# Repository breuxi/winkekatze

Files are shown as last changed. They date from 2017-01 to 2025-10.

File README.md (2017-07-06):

## ESP8266 enabled lucky cat

Code derived from https://github.com/themad/jimmykater

### Changes:
* Keeps lights on. So, continuous lighting.
* More light effects
* Keeps original waving mechanism. ( Instead of using a Servo )
* mqtt authentication support (can be configured in wifi captive portal)
* a lot of stuff

### MQTT Topics:

* catname/eye/mode/set   [solid|warp|blink]
* catname/eye/speed/set  [slow|med|fast]
* catname/eye/color/set  [dark|white|red|green|blue|yellow|cyan|pink]
* catname/paw/command    [wink|nowink]

### Demo Time!

<iframe src="https://player.vimeo.com/video/198570621" width="640" height="360" frameborder="0" webkitallowfullscreen mozallowfullscreen allowfullscreen></iframe>
<p><a href="https://vimeo.com/198570621">Monicat</a> from <a href="https://vimeo.com/user1086940">Bjoern Pohl</a> on <a href="https://vimeo.com">Vimeo</a>.</p>

### Hardware

Pinouts are currently set to a wemos d1 mini which fits nicely into such a cat. But I guess any 8266 excep a ESP01 will do it somehow. 

* 8266 : Wemos D1 Mini
  * at least three GPIOs:
    * "Force Setup" Button
    * LED Data input (only one for both leds, both could(!) be controlled individually, anyway.
    * Waving "electronic" from Cat :)
* pushbutton ( "force setup button")
* Cat : 22cm (~9 inch) lucky cat
* Adafruit addressable LEDs: https://www.sparkfun.com/products/12999
* 220 Ohm Resistor in Data line to the LEDs.
* A lot of hot glue.

The Sketch uses the famous [WifiManager](https://github.com/tzapu/WiFiManager). If you press the "force setup button" while powering the device, it'll loose all of it's settings and will fall back into WifiManager's AP mode.

Original lucky cat electronic can directly be driven by gpio (4-10mAh).

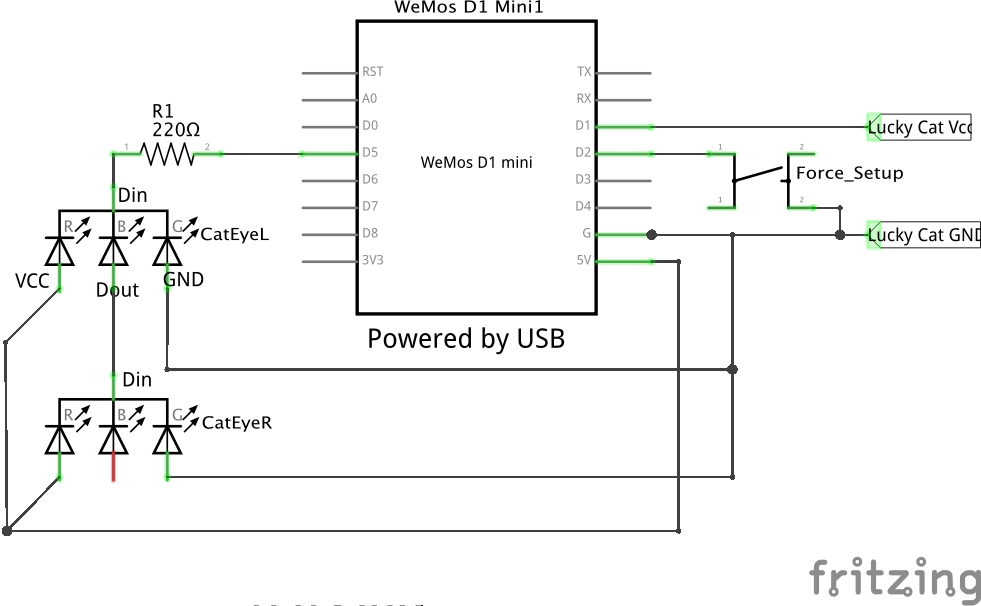
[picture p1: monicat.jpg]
Circuit Diagram


Code needs to be wiped through. A lot of Spaghetti and globals layin on the ground...

Blog Post here: https://www.datenwalze.de/post/monicat/

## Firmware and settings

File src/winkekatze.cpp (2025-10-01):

#include <FS.h>          // SPIFFS Filesystem
#include <ESP8266WiFi.h> //https://github.com/esp8266/Arduino
#include <PubSubClient.h>
#include <stdlib.h>
#include "FastLED.h"
FASTLED_USING_NAMESPACE

// WifiManager
#include <DNSServer.h>
#include <ESP8266WebServer.h>
#include <WiFiManager.h> //https://github.com/tzapu/WiFiManager
#include <ArduinoJson.h> //https://github.com/bblanchon/ArduinoJson

extern "C"
{
#include "user_interface.h"
}

char mqtt_server[255] = "";
char mqtt_port[6] = "1883";
char mqtt_username[34] = "";
char mqtt_password[34] = "";
char cat_name[34] = "fridolin";

//original wink electronic, directly connected to D1
const int servoPin = 5; //Wemos D1 Mini: "D1"

// LEDs connected to GPIO5. They are running with a lower voltage (around 4.3V) so the 3.3V output level is enough to trigger high
#if defined(FASTLED_VERSION) && (FASTLED_VERSION < 3001000)
#warning "Requires FastLED 3.1 or later; check github for latest code."
#endif

#define DATA_PIN 14
//#define CLK_PIN   4
#define LED_TYPE WS2811
#define COLOR_ORDER RGB
#define NUM_LEDS 2
CRGB leds[NUM_LEDS];
#define BRIGHTNESS 96
#define FRAMES_PER_SECOND 120
#define ARRAY_SIZE(A) (sizeof(A) / sizeof((A)[0]))
//Trigger pin for forced Setup
const int TRIGGER_PIN = 4; //Wemos D1 Mini: "D2"

//Timer, for changing color etc.
os_timer_t ledTimer;

WiFiClient espClient;
PubSubClient client(espClient);
long lastMsg = 0;
char msg[50];
int value = 0;
//for whatever reasons auto typedef didnt work...
void juggle();
void bpm();
void sinelon();
void confetti();
void addGlitter(fract8 chanceOfGlitter);
void rainbowWithGlitter();
void rainbow();

typedef void (*SimplePatternList[])();
SimplePatternList gPatterns = {rainbow, rainbowWithGlitter, confetti, sinelon, juggle, bpm};

uint8_t gCurrentPatternNumber = 0; // Index number of which pattern is current
uint8_t gHue = 0;                  // rotating "base color" used by many of the patterns
bool gColorcycle = 0;

void setup_wifi();
void callback(char *topic, byte *payload, unsigned int length);
void ledTimerCallback(void *pArg);

void eye_debug(struct CRGB pixel_color)
{
  Serial.println("Running Eye Debug");
  for (int dot = 0; dot < NUM_LEDS; dot++)
  {
    leds[dot] = pixel_color;
    FastLED.show();
  }
  Serial.println("finishing Eye Debug");
};

//flag for saving data
bool shouldSaveConfig = false;

void configModeCallback(WiFiManager *myWiFiManager)
{
  eye_debug(CRGB::Cyan);
}

//callback notifying us of the need to save config
void saveConfigCallback()
{
  Serial.println("Should save config");
  shouldSaveConfig = true;
}

void readConfig()
{
  //clean FS, for testing
  //SPIFFS.format();

  if (SPIFFS.begin())
  {
    Serial.println("mounted file system");
    if (SPIFFS.exists("/config.json"))
    {
      //file exists, reading and loading
      Serial.println("reading config file");
      File configFile = SPIFFS.open("/config.json", "r");
      if (configFile)
      {
        Serial.println("opened config file");
        size_t size = configFile.size();
        // Allocate a buffer to store contents of the file.
        std::unique_ptr<char[]> buf(new char[size]);

        configFile.readBytes(buf.get(), size);
        DynamicJsonBuffer jsonBuffer;
        JsonObject &json = jsonBuffer.parseObject(buf.get());
        json.printTo(Serial);
        if (json.success())
        {
          Serial.println("\nparsed json");

          strcpy(mqtt_server, json["mqtt_server"]);
          strcpy(mqtt_port, json["mqtt_port"]);
          strcpy(mqtt_username, json["mqtt_username"]);
          strcpy(mqtt_password, json["mqtt_password"]);
          strcpy(cat_name, json["cat_name"]);
        }
        else
        {
          Serial.println("failed to load json config");
        }
      }
    }
  }
  else
  {
    Serial.println("failed to mount FS");
  }
  //end read
}

void setup()
{
  // if we didn't use the serial output we could gain 2 GPIOs.
  Serial.begin(115200);

  Serial.write("monicat starts");

  // tell FastLED about the LED strip configuration
  FastLED.addLeds<LED_TYPE, DATA_PIN, COLOR_ORDER>(leds, NUM_LEDS).setCorrection(TypicalLEDStrip);
  //FastLED.addLeds<LED_TYPE,DATA_PIN,CLK_PIN,COLOR_ORDER>(leds, NUM_LEDS).setCorrection(TypicalLEDStrip);

  // set master brightness control
  FastLED.setBrightness(BRIGHTNESS);
  Serial.println("before 1st eye debug");
  eye_debug(CRGB::Green);
  Serial.println("after brightness control");
  //turn wink mechanism off
  pinMode(servoPin, OUTPUT);
  digitalWrite(servoPin, LOW);
  Serial.println("after servoPin setting");
  //check if Setup is enforced (user pressed Button while booting...)
  pinMode(TRIGGER_PIN, INPUT_PULLUP);

  if (digitalRead(TRIGGER_PIN) == LOW)
  {
    Serial.println("erasing filesystem");
    SPIFFS.format();
    ESP.eraseConfig();
  };
  Serial.println("before readConfig");
  readConfig();
  Serial.println("will setup wifi now");
  setup_wifi();

  client.setServer(mqtt_server, atoi(mqtt_port));
  client.setCallback(callback);

  eye_debug(CRGB::HotPink);
  delay(100);

  eye_debug(CRGB::Black);
  //arm Timer
  os_timer_setfn(&ledTimer, ledTimerCallback, NULL);
  os_timer_arm(&ledTimer, 10, true);
  Serial.println("end of setup");
}

void setup_wifi()
{
  // The extra parameters to be configured (can be either global or just in the setup)
  // After connecting, parameter.getValue() will get you the configured value
  // id/name placeholder/prompt default length
  WiFiManagerParameter custom_mqtt_server("server", "mqtt server", mqtt_server, 40);
  WiFiManagerParameter custom_mqtt_port("port", "mqtt port", mqtt_port, 5);
  WiFiManagerParameter custom_mqtt_username("mqtt_username", "mqtt username", mqtt_username, 34);
  WiFiManagerParameter custom_mqtt_password("mqtt_password", "mqtt password", mqtt_password, 34);
  WiFiManagerParameter custom_cat_name("cat_name", "the cat's name", cat_name, 32);

  WiFiManager wifiManager;

  Serial.println("in setup wifi now");
  eye_debug(CRGB::Blue);
  //set config save notify callback

  //also reset wifi settings when pressed...
  if (digitalRead(TRIGGER_PIN) == LOW)
  {
    wifiManager.resetSettings();
  };

  wifiManager.setSaveConfigCallback(saveConfigCallback);
  wifiManager.setAPCallback(configModeCallback);

  //add all your parameters here
  wifiManager.addParameter(&custom_mqtt_server);
  wifiManager.addParameter(&custom_mqtt_port);
  wifiManager.addParameter(&custom_mqtt_username);
  wifiManager.addParameter(&custom_mqtt_password);
  wifiManager.addParameter(&custom_cat_name);

  wifiManager.setConfigPortalTimeout(600);

  if (!wifiManager.autoConnect("Winkekatze", "geheimgeheim"))
  {
    eye_debug(CRGB::Red);
    Serial.println("failed to connect and hit timeout");
    delay(3000);
    //reset and try again, or maybe put it to deep sleep
    ESP.reset();
    delay(5000);
  }

  //read updated parameters
  strcpy(mqtt_server, custom_mqtt_server.getValue());
  strcpy(mqtt_port, custom_mqtt_port.getValue());
  strcpy(mqtt_username, custom_mqtt_username.getValue());
  strcpy(mqtt_password, custom_mqtt_password.getValue());
  strcpy(cat_name, custom_cat_name.getValue());

  //save the custom parameters to FS
  if (shouldSaveConfig)
  {
    Serial.println("saving config");
    DynamicJsonBuffer jsonBuffer;
    JsonObject &json = jsonBuffer.createObject();
    json["mqtt_server"] = mqtt_server;
    json["mqtt_port"] = mqtt_port;
    json["mqtt_username"] = mqtt_username;
    json["mqtt_password"] = mqtt_password;
    json["cat_name"] = cat_name;

    File configFile = SPIFFS.open("/config.json", "w");
    if (!configFile)
    {
      Serial.println("failed to open config file for writing");
    }

    json.printTo(Serial);
    json.printTo(configFile);
    configFile.close();
    //end save
  }
}

void callback(char *topic, byte *payload, unsigned int length)
{
  Serial.print("Callback! Topic:  ");
  Serial.print(String(topic));
  Serial.print("\n");

  if (String(topic) == String(cat_name) + "/paw/command")
  {
    char *p = (char *)malloc(length + 1);
    p[length] = 0;

    // Copy the payload to the new buffer
    memcpy(p, payload, length);

    String winkstr(p);

    Serial.print("/paw/command Payload: ");
    Serial.print(winkstr);
    Serial.print("\n");
    if (winkstr == "wink")
    {
      digitalWrite(servoPin, HIGH);
    }
    else if (winkstr == "nowink")
    {
      digitalWrite(servoPin, LOW);
    }

    free(p);
  }
  else if (String(topic) == String(cat_name) + "/command" || String(topic) == "winkekatze/allcats")
  {
    //TODO: do something that all cats need to do
  }
  else if (String(topic) == String(cat_name) + "/eye/hue/set")
  {
    char *p = (char *)malloc(length + 1);
    p[length] = 0;

    // Copy the payload to the new buffer
    memcpy(p, payload, length);

    String colstr(p);
    //  if ( colstr == "pink" ) {
    Serial.print("Color Payload: ");
    Serial.print(colstr);
    Serial.print("\n");
    gHue = colstr.toInt() % 256;
    free(p);
  }
  else if (String(topic) == String(cat_name) + "/eye/colorcycle/set")
  {
    char *p = (char *)malloc(length + 1);
    p[length] = 0;

    // Copy the payload to the new buffer
    memcpy(p, payload, length);

    String cyclestr(p);
    //  if ( colstr == "pink" ) {
    Serial.print("colorcycle Payload: ");
    Serial.print(cyclestr);
    Serial.print("\n");
    gColorcycle = cyclestr.toInt() % 2;
    free(p);
  }
  else if (String(topic) == String(cat_name) + "/eye/brightness/set")
  {
    char *p = (char *)malloc(length + 1);
    p[length] = 0;

    // Copy the payload to the new buffer
    memcpy(p, payload, length);

    String brtstr(p);
    Serial.print("Brightness Payload: ");
    Serial.print(brtstr);
    Serial.print("\n");
    FastLED.setBrightness(brtstr.toInt() % 256);
    free(p);
  }
  else if (String(topic) == String(cat_name) + "/eye/mode/set")
  {
    char *p = (char *)malloc(length + 1);
    p[length] = 0;

    // Copy the payload to the new buffer
    memcpy(p, payload, length);

    String modestr(p);

    Serial.print("Mode Payload: ");
    Serial.print(modestr);
    Serial.print("\n");
    int mode = modestr.toInt();
    gCurrentPatternNumber = mode % ARRAY_SIZE(gPatterns);
  }
  client.publish((String(cat_name) + "/status").c_str(), "fishing");
}

void ledTimerCallback(void *pArg)
{
  // Call the current pattern function once, updating the 'leds' array
  gPatterns[gCurrentPatternNumber]();

  // send the 'leds' array out to the actual LED strip
  FastLED.show();
}

void reconnect()
{
  // Loop until we're reconnected
  while (!client.connected())
  {
    Serial.print("Attempting MQTT connection...");
    Serial.print("mqtt_username:");
    Serial.print(mqtt_username);
    Serial.print(", mqtt_password:");
    Serial.print(mqtt_password);
    Serial.print(", mqtt_server:");
    Serial.print(mqtt_server);
    Serial.print("\n Attempting MQTT connection...");

    // Attempt to connect
    if (client.connect(cat_name, mqtt_username, mqtt_password, (String(cat_name) + "/connected").c_str(), 2, true, "0"))
    {
      Serial.println("connected");
      eye_debug(CRGB::Green);
      delay(100);
      eye_debug(CRGB::Black);
      // Once connected, publish an announcement...
      client.publish((String(cat_name) + "/connected").c_str(), "1", true);
      // ... and resubscribe
      client.subscribe((String(cat_name) + "/paw/command").c_str());
      client.subscribe((String(cat_name) + "/command").c_str());
      client.subscribe("winkekatze/allcats");
      client.subscribe((String(cat_name) + "/eye/hue/set").c_str());
      client.subscribe((String(cat_name) + "/eye/brightness/set").c_str());
      client.subscribe((String(cat_name) + "/eye/mode/set").c_str());
      client.subscribe((String(cat_name) + "/eye/speed/set").c_str());
      client.subscribe((String(cat_name) + "/eye/colorcycle/set").c_str());
    }
    else
    {
      Serial.print("failed, rc=");
      Serial.print(client.state());
      Serial.println(" try again in 2 seconds");
      eye_debug(CRGB::Red);
      delay(100);
      eye_debug(CRGB::Black);
      // Wait 2 seconds before retrying
      delay(1900);
    }
  }
}

void loop()
{
  if (!client.connected())
  {
    reconnect();
  }
  client.loop();
  //if colorcycle is on, rotate colors
  EVERY_N_MILLISECONDS(20)
  {
    if (gColorcycle)
    {
      gHue++;
    }
  }
}

void rainbow()
{
  // FastLED's built-in rainbow generator
  fill_rainbow(leds, NUM_LEDS, gHue, 7);
}

void rainbowWithGlitter()
{
  // built-in FastLED rainbow, plus some random sparkly glitter
  rainbow();
  addGlitter(80);
}

void addGlitter(fract8 chanceOfGlitter)
{
  if (random8() < chanceOfGlitter)
  {
    leds[random16(NUM_LEDS)] += CRGB::White;
  }
}

void confetti()
{
  // random colored speckles that blink in and fade smoothly
  fadeToBlackBy(leds, NUM_LEDS, 10);
  int pos = random16(NUM_LEDS);
  leds[pos] += CHSV(gHue + random8(64), 200, 255);
}

void sinelon()
{
  // a colored dot sweeping back and forth, with fading trails
  fadeToBlackBy(leds, NUM_LEDS, 20);
  int pos = beatsin16(13, 0, NUM_LEDS - 1);
  leds[pos] += CHSV(gHue, 255, 192);
}

void bpm()
{
  // colored stripes pulsing at a defined Beats-Per-Minute (BPM)
  uint8_t BeatsPerMinute = 62;
  CRGBPalette16 palette = PartyColors_p;
  uint8_t beat = beatsin8(BeatsPerMinute, 64, 255);
  for (int i = 0; i < NUM_LEDS; i++)
  { //9948
    leds[i] = ColorFromPalette(palette, gHue + (i * 2), beat - gHue + (i * 10));
  }
}

void juggle()
{
  // eight colored dots, weaving in and out of sync with each other
  fadeToBlackBy(leds, NUM_LEDS, 20);
  byte dothue = 0;
  for (int i = 0; i < 8; i++)
  {
    leds[beatsin16(i + 7, 0, NUM_LEDS - 1)] |= CHSV(dothue, 200, 255);
    dothue += 32;
  }
}

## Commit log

2017-01-08 Added circuit diagram
    [monicat.fzz]
2017-01-08 fzz update
    [monicat.fzz]
2017-07-06 some docu about setup button
